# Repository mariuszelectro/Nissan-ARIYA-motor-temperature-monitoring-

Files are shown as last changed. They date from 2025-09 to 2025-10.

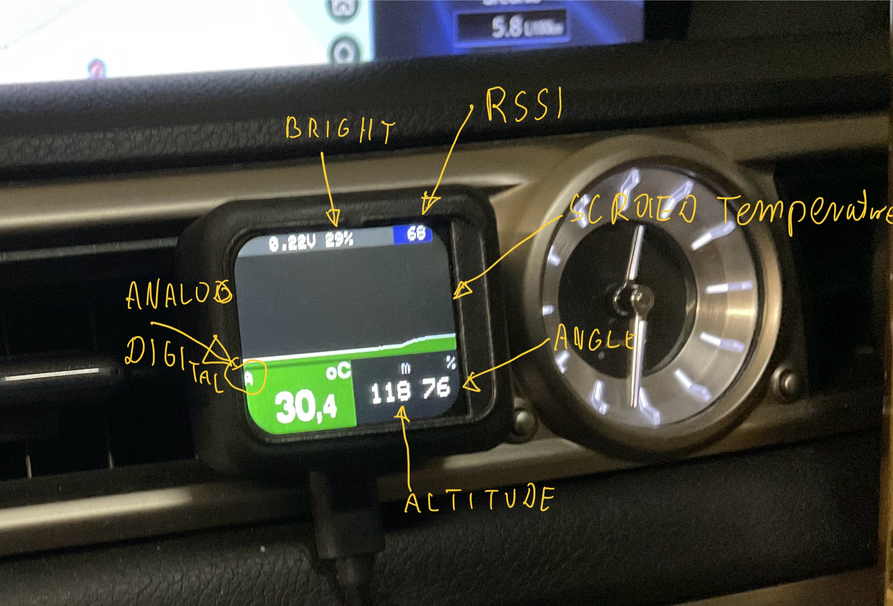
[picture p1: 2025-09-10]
ExtraInfo/IMG_2104.jpeg

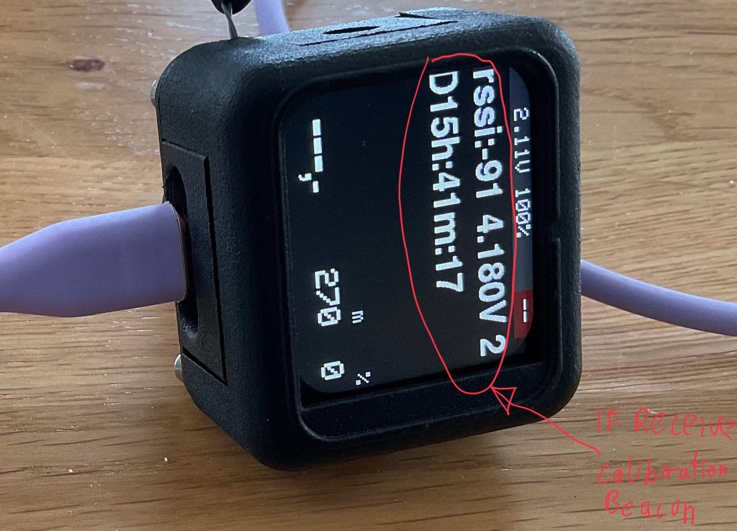
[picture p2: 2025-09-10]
ExtraInfo/IMG_2107.jpeg

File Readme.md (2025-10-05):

# Nissan Ariya Electric Motor Temperature Monitor
Kup mi kawę (https://www.buymeacoffee.com/mariuszelectro)

This project aims to create an independent system to monitor the electric motor's temperature in a Nissan Ariya. The system is designed to prevent sudden vehicle shutdowns caused by overheating.
This project was created as hobby not for comercial  use with maximise effect, not method.

---
### Project Background

The Nissan Ariya has a serious software flaw that can lead to dangerous situations. While driving on an incline, the motor's temperature can rise rapidly, and the car's system will cut power without warning. This can cause the vehicle to stop suddenly on a sloped road in the midle, creating a significant road safety hazard. Since there are no off-the-shelf monitoring systems available to address this problem, I've decided to build one myself.

---
### Key Features

* **Dual Temperature Sensors:** The system uses two diffrent sensors for precise temperature measurement. First Analg PT100, second digital DS18B20
* **Wireless Data Transmission:** Temperature status is sent wirelessly in real-time, trough BLE
* **Temperature Trend Analysis:** The software analyzes the rate of temperature increase, not just the current temperature level, which helps predict potential overheating events.
* **Fast Data Refresh:** Status information is refreshed and analyzed in less than one second.
* **Receiver Unit:** The receiver is equipped with a 1.69" LCD, a buzzer for alerts, a barometric pressure sensor to display altitude, and an inclinometer to show the road's tilt.
* **Receiver function:** The receiver present tempeperature as osciloscope digram for easy understand trends, alitude, and road's tilt.
* **Smart Functions:** A photoresistor automatically adjusts the display's brightness and can also be used as a button to silence the alarm.
* **Calibrator:** Optional Third party used for calibrate sensors.
* **Custom Housing:** All enclosures were designed using 3D modeling and are printed with MJF technology using Nylon for durability.
* **Cost-Effective:** Most of the necessary components can be purchased online at low prices.
* **AI-Powered Code:** A significant portion of the code was developed with the assistance of Gemini AI, but tested and coreted with me.

### Category	Technologies/Skills Demonstrated
* **Electronics Design:** Design of devices containing Analog Circuits and Digital Circuits using Microcontrollers.
* **PCB Design:** Professional PCB Design using Altium Designer (Printed Circuit Board layout).
* **Software & Programming:** Programming in C/C++ (real-time logic, BLE communication, and data analysis).
* **Electro-Mechanical:** Design	Electro-Mechanical Design and physical integration of electronics into custom enclosures.
* **3D Modeling & Enclosures:** 3D Modeling of custom enclosures using FreeCAD, with subsequent manufacturing via MJF 3D Printing.
* **Communication& Data:** Bluetooth Low Energy (BLE) implementation and custom algorithm development for Temperature Trend Analysis.

* * **My contact:** mariuszelectro@gmail.com

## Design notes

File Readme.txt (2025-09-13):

Environment:
ardiuno IDE for upload code
Version: 2.3.6
Date: 2025-04-09T11:26:55.498Z
CLI Version: 1.2.0
------------------
Compile and Editor Eclipse C++ and extension Sloeber https://marketplace.eclipse.org/content/sloeber-arduino-plugin-eclipse 
--------------------------------------------
platform Seeed nRF52 boards version 1.1.10  (sense version) for receiver (need high performance of display by SPI) 
--------------------------------------------
libraries:
Adafriut BMP280 2.6.8
Adafriut BUSIO 1.17.2
Adafriut GFX Library 1.12.1
Adafriut NeoPixel 1.15.1
Adafriut ST7735 and ST7789 Library 1.11.0
Adafriut Unified Sensor 1.1.15
Seeed Arduino LSM6D3 2.0.4  (from SEEED github) please don't add or remove tinyUSB !!!!
----------------------------------------------------------------------------------------
other library installed used form other part of project like transmiter or calibrator
MaximWire by xeno 1.0.3
ArdiunoBLE 1.4.0  (pls don't update! not work in my case )
Adafriut BlueFruitLE nRF51 1.10.0
NRF52_MBED_Timer by Khoi Hoang 1.4.1
NRF52_Timerinterrupt by Khoi Hoang 1.4.2
ardiuno-NVM by frank Holz 0.9.1 (with source code deep modyfication) for future use, now not used 
-----------------------------------------------------------------------------------
platform  Seeed nRF52 mbebd enabled Boards 2.9.3 (for transmiter) 
platform Seeed nRF52 boards version 1.1.10 (for calibrator)

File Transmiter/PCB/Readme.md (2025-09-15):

Here yu will finad all fiels to make an PCB. you can order this usind any suplier.
Thre are 4 layer PCB production gerber, schematic and other files neccessyry for this project. 
Enjoyed.

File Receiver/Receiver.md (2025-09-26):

### **1. Main Module**

---

* **Name:** XIAO nRF52840 Sense
* **Key Features:**
    * Built-in 6-axis Inertial Measurement Unit (IMU) based on a gyroscope and accelerometer for motion and orientation measurement.
    * Bluetooth Low Energy (BLE) module for wireless communication with the transmitter.

---

### **2. Display**

---

* **Type:** 1.69-inch LCD display (based on the [Waveshare 1.69inch LCD Module](https://www.waveshare.com/wiki/1.69inch_LCD_Module))
* **Interface:** Communicates via an SPI (Serial Peripheral Interface) bus.
* **Function:** Used for visualizing data, such as sensor measurements, device status, or other project information.

---

### **3. Sensors**

---

* **Pressure and Temperature Sensor:**
    * **Name:** BMP280 (based on the [HiLetgo BMP280](https://www.amazon.com/HiLetgo-Precision-BMP280-3-3-Atmospheric-Pressure/dp/B01ICN5QPU?th=1))
    * **Characteristics:** A barometric sensor that measures atmospheric pressure for altitude calculation, i2c imtrface. Requires a version with two mounting holes for mechanical stabilization of the XIAO module within the enclosure.
    * **Function:** Used **exclusively** for measuring altitude based on pressure readings.

* **Photoresistor:**
    * **Name:** GL5537 (5537 series)
    * **Characteristics:** A light sensor whose resistance changes with light intensity. 5 mm diameter. ([Link to GL5537 photoresistor](https://juriedengineering.com/products/gl5537-photo-light-sensitive-resistor-photoresistor-55375mm))
    * **Function:** Used to measure ambient light levels.

---

### **4. Audio Components**

---

* **Buzzer:**
    * **Type:** A passive buzzer, converted to active.
    * **Characteristics:** 12mm x 7.5mm in size.
    * **Function:** Used to generate audio signals, alarms, or notifications.

---

### **5. Enclosure and Power Supply**

---

* **Type:** A two-part screw-fastened enclosure.
* **Production Technology:** Printed in **MJF** (Multi Jet Fusion) 3D technology.
* **Function:** Provides precise and secure mechanical mounting for all internal electronic components.
* **Mounting:**
    * **Options:** Magnetic or screw-based mounting.
    * **Location:** Car air vent holder or a standard magnetic mount.
* **Power Supply:** USB-C port.
* **Power Consumpion:** 20mA@5V in dark mode, 50mA@5V in Bright mode

---

### **6. Software Functionality**

---

* **BLE Communication:**
    * **Mode:** The device operates in **passive listener** (beacon passive listener) mode.
    * **Characteristics:** It does not establish an active Bluetooth (BT) connection in any profile. It receives broadcast data from an external measurement beacon.
    * **Received Data:**
        * Temperature from an analog sensor.
        * Temperature from a digital sensor.
        * Fan status.
        * Alarm status.
        * A control counter (ensures data is not duplicated).

* **User Interface (LCD Display):**
    * **Screen Structure:** Divided into several sections.
    * **Sections:**
        * **Title Bar:** Contains the title and **status flags** (e.g., connection status, alarm).
        * **RSSI Section:** Displays the signal strength (RSSI) of the transmitter.
        * **Temperature Oscillogram:** Graphical bars drawn on the screen corresponding to the measured temperature value. They automatically scroll to the left every second. This uses the **display controller's hardware mechanisms**.
        * **Temperature Value:** A numerical indication of the current temperature.
        * **Altitude:** Displays the current altitude.
        * **Road Incline Angle:** The road's incline angle value, shown in a percentage.
    * **Dynamic Backgrounds:** The oscillogram and temperature value sections have defined background colors that change depending on the measured temperature range.

* **Photoresistor Operation:**
    * **Function 1 (Brightness):** Measures external light intensity for automatic screen brightness adjustment (dark and light modes).
    * **Function 2 (Virtual Button):** Acts as a button for calibration. Activated by covering it for 10 seconds after the vehicle starts.
    * **Function 3 (Alarm):** Allows the user to silence an active alarm.
    * **Note:** All measurements for brightness and "presses" are filtered in software to prevent flickering or accidental triggers.

* **Buzzer Operation:**
    * **Characteristics:** Active and dynamic.
    * **Dependencies:** The tone and length of the generated sound depend on the type of alarm and any further temperature increase. The duration and tone of each beep is variable.

* **Sensor Calibration:**
    * **Sensor Types:** Barometric and position (gyroscope/accelerometer).
    * **Calibration Methods:**
        1.  **Button Press:** Manual calibration activation.
        2.  **Signal Reception:** Automatic calibration upon receiving a signal from a dedicated calibration beacon "Calibrator"
    * **Calibration Process:**
        * **Inclinometer:** Zeros the incline angle readings to a zero position, regardless of the device's current orientation.
        * **Pressure:** Compensates absolute pressure for a fixed altitude of 270 meters above sea level.
    * **Calibration Availability:** The calibration function is available **only within a 10-second time window after the device is powered on**.
    * **Accuracy:** The altitude measurement has an accuracy of approximately 1 meter.

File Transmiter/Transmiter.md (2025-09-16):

# Nissan Ariya - Advanced Electric Motor Temperature Monitor

This project aims to create an independent, intelligent system for monitoring and actively managing the electric motor's temperature in a Nissan Ariya. The primary goal is to prevent sudden, dangerous vehicle shutdowns caused by overheating.

---

### Transmitter Assumptions and Functions

The transmitter is the core of the system, focusing on advanced data analysis and control that goes beyond simple temperature readings.

#### Inputs and Power
* **Inputs:** The transmitter has three inputs:
    1.  A dedicated input for a **PT100** sensor.
    2.  An input for a digital **DS18B20** sensor.
    3.  A power input ranging from **12-16V** from the car's on-board network.
* **Power Management:** A comparator-based circuit monitors the 12V battery voltage. The system activates at **13.6V** and enters a low-power sleep mode at **12.9V** (with hysteresis), consuming only 3µA in standby mode and 30mA in opertional mode 

#### Measurement Circuitry
* **PT100 Measurement:** The input circuit consists of a Wheatstone bridge with three **105R resistors** (0.1% tolerance, low ppm). This specific resistance value was chosen because the project focuses on temperatures **above 15°C**. The bridge is powered by a ~2mA current source, and the resulting voltage signal is amplified by an instrumental amplifier.
* **Signal Conversion:** The voltage is converted to a **0-12V** level and then fed through a voltage divider to the measurement input of a **XIAO nRF52840** module.
* **Data Processing:** The XIAO module samples the voltage every few milliseconds, applies filtering and advanced averaging, and then converts the voltage value into a temperature reading. It also handles the digital DS18B20 sensor.

---

### Sensor Selection: Why Two?

Although using a single, digital **DS18B20** sensor would simplify the circuit, past experience shows it's susceptible to interference from strong magnetic fields, which causes it to **freeze or hang**. To ensure reliability and continuous measurements, a redundant sensor setup with two different types of sensors was implemented. **By cycling the power, the system can restore the sensor to operation.** The system intelligently selects the proper, available sensor by analyzing both signals.

---

### Advanced Logic and Control
* **Sensor Selection:** The system analyzes data from both sensors, always selecting the one that is available and has a higher temperature reading.
* **Trend Analysis:** The software analyzes the temperature's upward trend, predicting its increase over a **30-second period**.
* **Early Warning:** An alarm is activated well in advance if the trend analysis predicts the temperature will reach the critical limit of **70°C**. You can set another one.
* **Actuator Control:** An output is available to control an external actuator, such as an **additional cooling fan**. The fan's activation is also based on the temperature trend analysis.
* **Analog Output:** An analog output signal (0-12V) is provided for diagnostic purposes, where **10V corresponds to 100°C**.
* **Control Method:** The fan can be controlled via a hardware comparator or by software.

#### Communication and Housing
* **BLE Beacon Mode:** The XIAO module operates as a BLE "beacon," transmitting measurement data, alarm flags, fan status, and a running counter as dynamic advertising data. This allows it to be tracked with a standard Bluetooth scanner on a phone.
* **Debug Mode:** When connected, the module enters a debug mode (SSP BLE profile ), sending data to the Bluefruit Connect application to generate plots on canvas, from both sensors.
* **Antenna:** The custom PCB version includes a modified antenna layout with a u.FL connector for an external antenna, providing better range than the factory one.
* **Enclosure:** The housing is 3D printed using MJF technology with black nylon powder, resulting in a very solid and durable enclosure with 3mm thick walls, labyrinthine seals, and cable holders.
* **Availability:** The PCB schematic BOM and layout you can find in PCB section . While others can print the model using different technologies, the precise fit and accuracy of the MJF process may not be achievable.

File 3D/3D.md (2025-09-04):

### 3D Models (Source Files)

Here you will find the 3D models (source files) created in **FreeCAD**. The models are designed for 3D printing.

In the future, these models will be supplemented with `.stl` files.

You can open the `.FCStd` file in FreeCAD to make changes and export the models of individual components.

---
#### List of 3D Models

* Car air vent mount
* LCD display housing (top and bottom parts)
* Transmitter sensor housing (top and bottom parts)

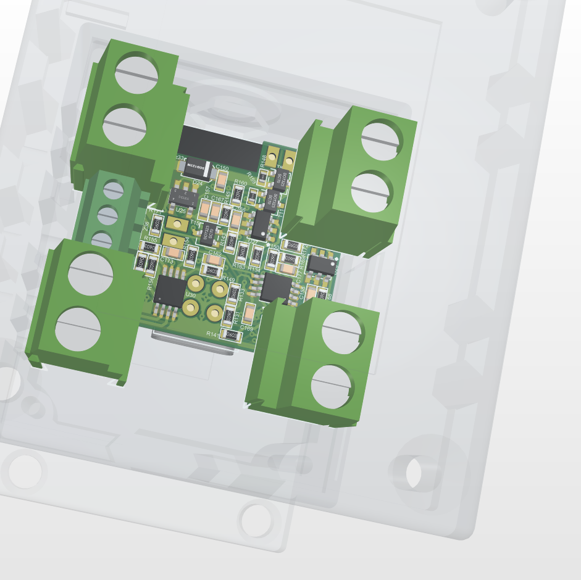
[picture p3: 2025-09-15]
ExtraInfo/YpadjyPY0odjasRK.png

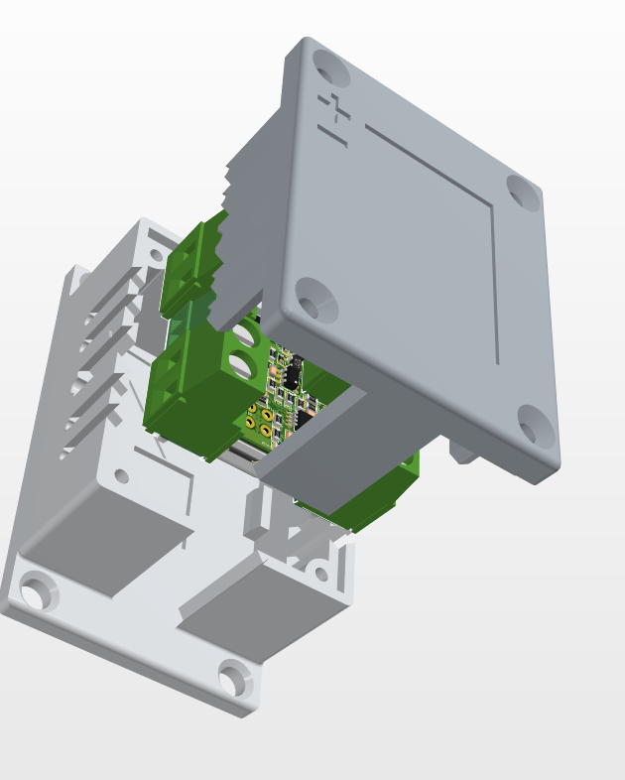
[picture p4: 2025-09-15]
ExtraInfo/zAJwUcnX5S6KeYe2.png

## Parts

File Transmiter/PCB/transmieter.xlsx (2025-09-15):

Comment | Description | Designator | dostawca | Footprint | Quantity
1u/16V 10% X7R | C | C150, C157, C162, C167, C168, C169, C173 |  | 0603-CAP | 7
100n/16V 10% X7R | C | C158, C166, C174, C177 |  | 0603-CAP | 4
PMEG150G20ELRX | 1A 100V (min) | D24 |  | SOD123W | 1
S-GW120 | LED | D25 |  | 0805-LED-G | 1
UCLAMP3301D.TCT | dioda zenera 3.3V | D26 |  | SOD323 | 1
300K 1% | REZ | R24, R148, R159, R162 |  | 0402-REZ | 4
10K 0,1% 25ppm | REZ | R131, R133, R141 |  | 0603-REZ | 3
4M7 1% | REZ | R134, R172 |  | 0603-REZ | 2
390R 1% | REZ | R142 |  | 0603-REZ | 1
220K 1% | REZ | R143, R168 |  | 0603-REZ | 2
191K 1% | REZ | R144 |  | 0603-REZ | 1
150K 1% | REZ | R145 |  | 0603-REZ | 1
105R 01% 25ppm | REZ | R146, R147, R151 |  | 0603-REZ | 3
0R | REZ | R149 |  | 0603-REZ | 1
1M 1% | REZ | R150, R154, R163 |  | 0603-REZ | 3
DNP | REZ | R155, R158, R171 |  | 0603-REZ | 3
931R 0,1% 25ppm | REZ | R156, R157 |  | 0603-REZ | 2
1M5 1% | REZ | R160 |  | 0603-REZ | 1
45K3 1% | REZ | R161 |  | 0603-REZ | 1
4K7 1% | REZ | R164 |  | 0603-REZ | 1
10K 1% | REZ | R165 |  | 0603-REZ | 1
3k9 1% | REZ | R167 |  | 0603-REZ | 1
270K 1% | REZ | R169 |  | 0603-REZ | 1
PJC7439 |  | T8, T16 |  | sot-323 | 2
2N7002BKW.115 |  | T11, T17, T18 |  | sot-323 | 3
AO7407 |  | T15 |  | sot-323 | 1
TPS7A2450DBVR | 200-mA, 18-V, ultra-low-IQ, low-dropout (LDO) voltage regulator with enable | U25 |  | SOT223-5 | 1
TLV9352 | dual op ampl 40V TLV9352IDGKR | U26 |  | msop8 | 1
MCP65R46T-1202E/CHY | komparator +ref | U27, U29 |  | sot23-6 body2.2x2.7mm | 2
xiao-nRF52840 | xiao-nRF52840 | U28 |  | XiAO-nRF52840 | 1
INA333 | AD623 | U30 |  | msop8 | 1
ARK2 |  | z32, z33, z34, z35 | [NoParam], wurth 691502710002 | ARK2 5.0mm | 4
wurth 691212710003 |  | Z36 |  | ARK 3x2.54mm | 1

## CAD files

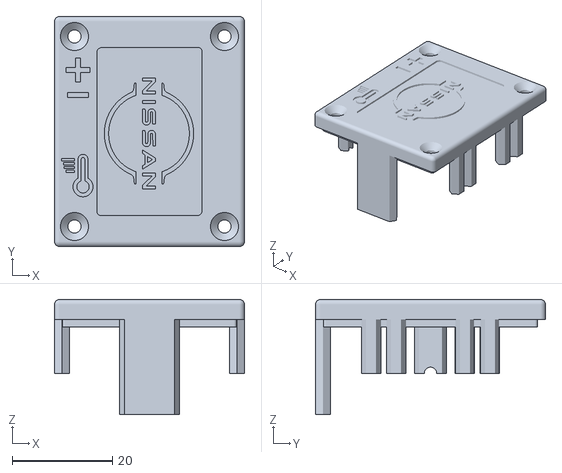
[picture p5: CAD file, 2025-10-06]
3D/TempSensorPTC100_wieczko-Body.stl
38.0 x 46.0 x 23.0

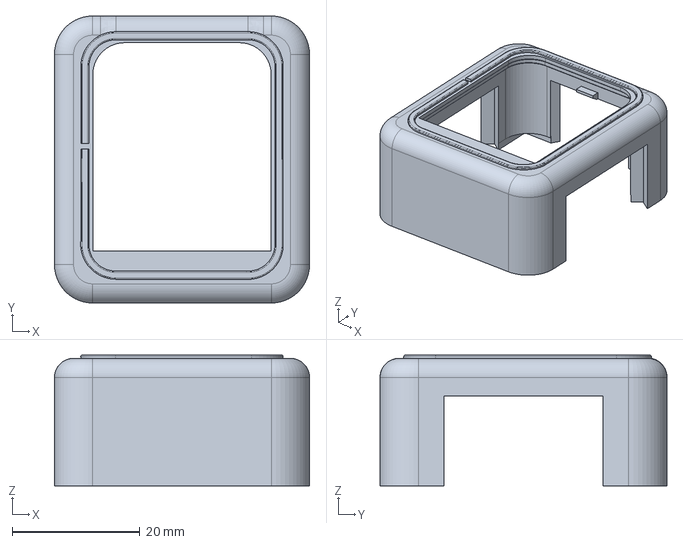
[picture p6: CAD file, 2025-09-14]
3D/LCD_topV2.FCStd
40.0 x 45.0 x 20.5 mm

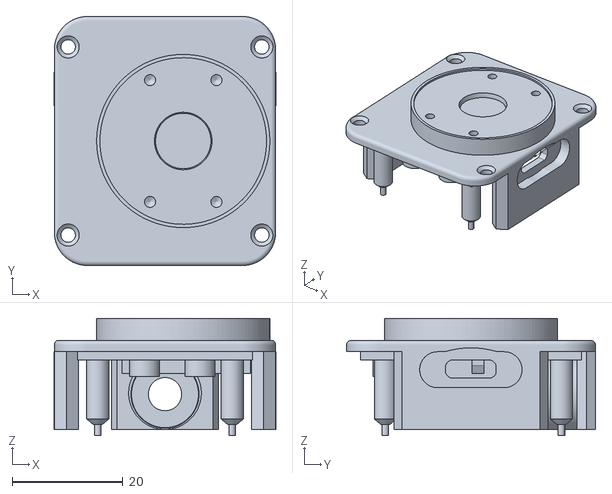
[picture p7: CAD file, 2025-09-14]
3D/LCD_bottomV1-Body.stl
40.0 x 45.0 x 21.2

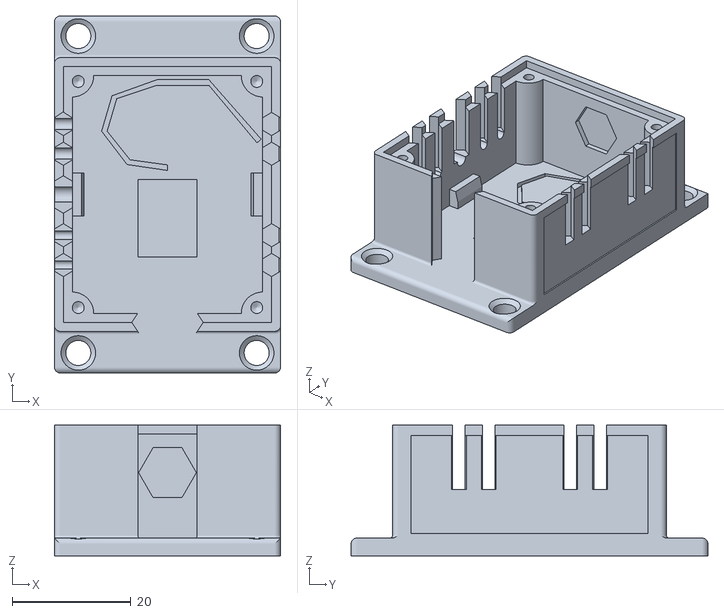
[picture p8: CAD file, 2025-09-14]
3D/TempSensorPTC100v1-Body.stl
38.0 x 60.0 x 22.0

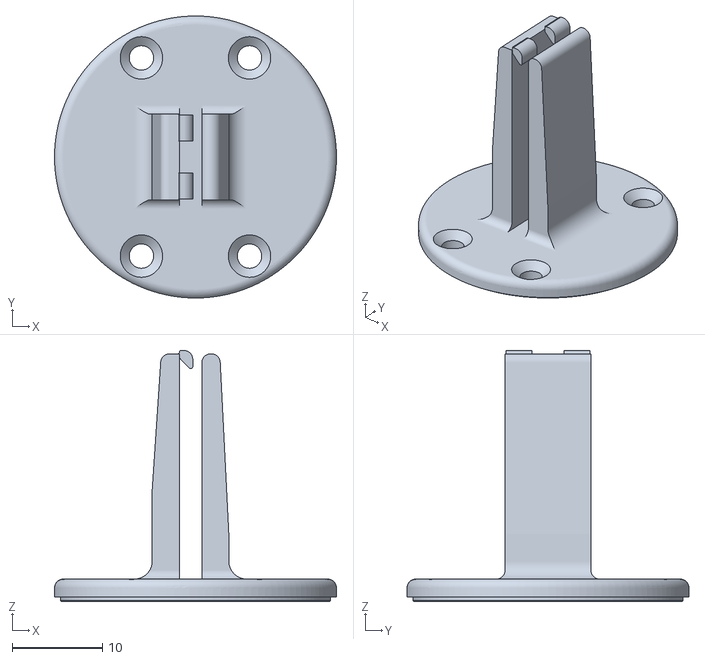
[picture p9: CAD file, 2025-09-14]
3D/uchwyt-Bodyv1.stl
31.3 x 31.3 x 27.9

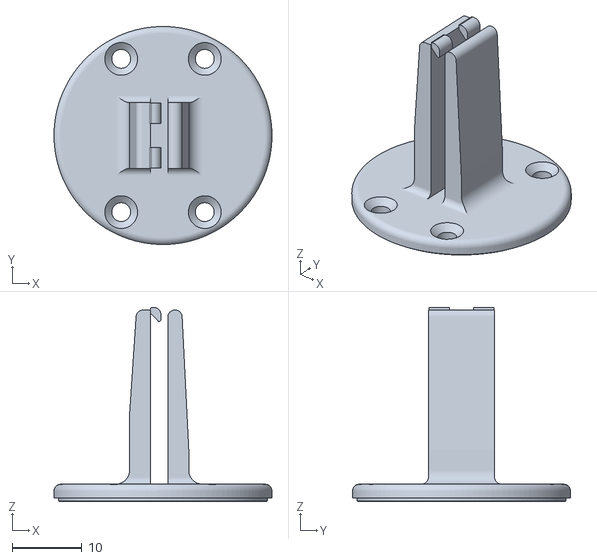
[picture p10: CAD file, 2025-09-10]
3D/uchwyt-Body.stl
31.3 x 31.3 x 27.9

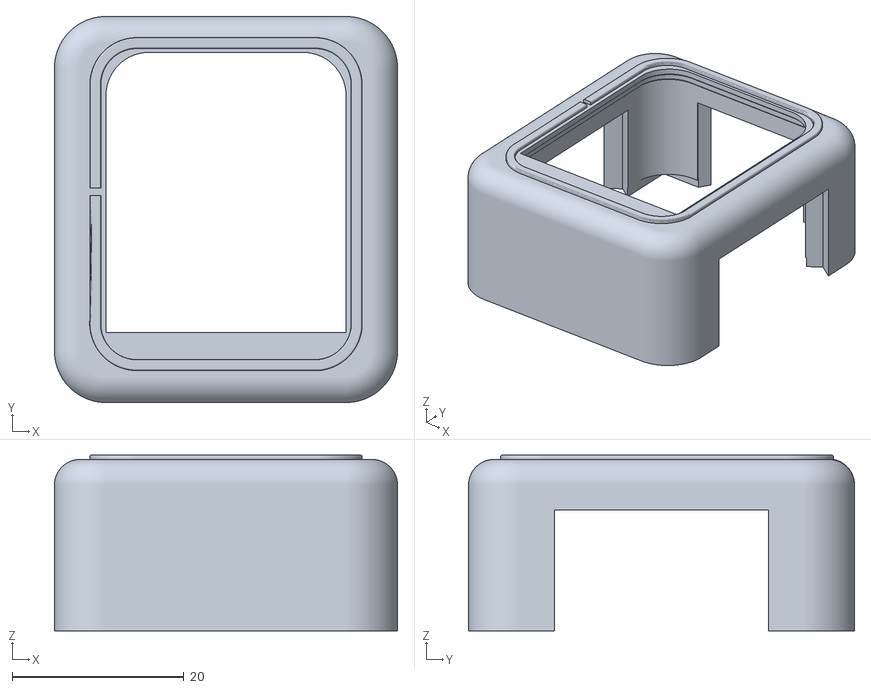
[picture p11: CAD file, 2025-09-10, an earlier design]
3D/LCD_topV1-Body.stl
40.0 x 45.0 x 20.5

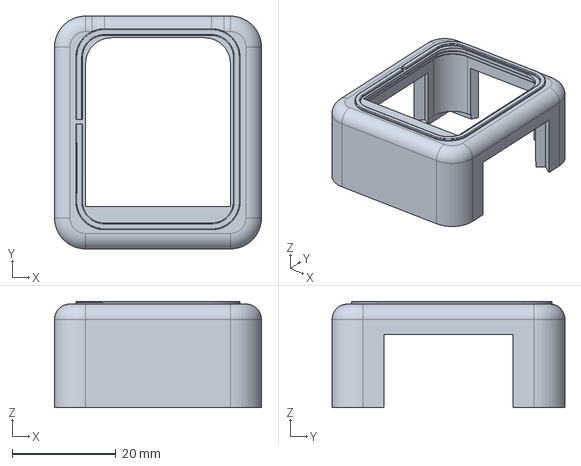
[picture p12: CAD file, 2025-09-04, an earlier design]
3D/LCD_topV1.FCStd
40.0 x 45.0 x 20.5 mm

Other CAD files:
3D/TempSensorPTC100_wieczko.FCStd
3D/LCD_topV2-Body.stl
3D/LCD_bottomV1.FCStd
3D/TempSensorPTC100.FCStd
3D/uchwytv1.FCStd
3D/TempSensorPTC100v1.FCStd
3D/TempSensorPTC100-Body.stl
3D/uchwyt.FCstd

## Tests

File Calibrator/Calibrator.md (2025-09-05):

---
# Calibrator

Calibrator is a smart auxiliary device designed for automatic calibration of a vehicle's altitude and road incline sensors. It uses **Bluetooth Low Energy (BLE)** technology to communicate with the car, ensuring precise settings right after the ignition.

## How it Works

The Calibrator device is placed in a garage or another stable, fixed location. When the car is started, the vehicle's system actively scans its surroundings for a calibration beacon for the first 10 seconds.

* **Barometric Sensor (Altimeter) Calibration:** If the signal is detected, the vehicle's barometric sensor is automatically calibrated to a predefined, fixed altitude.
* **Inclinometer Calibration:** At the same time, with the vehicle on a level surface, the software sets the inclinometer's reading to 0 degrees, eliminating measurement errors.

After a successful calibration, a scrolling message appears on the car's receiver, confirming the calibration and displaying the beacon's **battery voltage** and **uptime** since its last power-on.

## Technical Aspects

* **Platform:** The project is built on the energy-efficient **XIAO nRF52840** platform, which provides high performance with minimal power consumption.
* **Power:** The device is powered by a single **18650 battery**. Thanks to its exceptional power efficiency, the battery can operate the device for **5-10 years** without needing to be recharged. If needed, it can be easily topped up via the built-in **USB-C** port.
* **BLE Communication:** The Calibrator device broadcasts a beacon signal that includes real-time information about its **current battery voltage** and **uptime**, allowing you to monitor the device's status directly from the car.

---

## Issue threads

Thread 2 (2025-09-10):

Receiver virtual button not work when is very bright

mariuszelectro, 2025-09-10:
Virtual button need update. When ambient light is high luminance there is no possibles do calibration or mute alarm.
Why because finger is no enough for cut light and activate sensor.
Solution introduce dynamic level of activate instead of fixed.

mariuszelectro, 2025-09-27:
Resolved by inroducing dynamic level depend on ambient bright.

Closed 2025-09-27.

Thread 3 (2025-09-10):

Road profile not working

mariuszelectro, 2025-09-10:
Imu sensor is sensitive for vibration and acceleration, so road profile is absolute false. solution introduce hardware filter for reduce noise, use advanced filtering for compensate.

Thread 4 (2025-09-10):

Receiver save calibration

mariuszelectro, 2025-09-10:
Save gyro relative x,y,z axis seems like sometimes not save or read properly. Need deeper investigation.

Closed 2025-09-27.

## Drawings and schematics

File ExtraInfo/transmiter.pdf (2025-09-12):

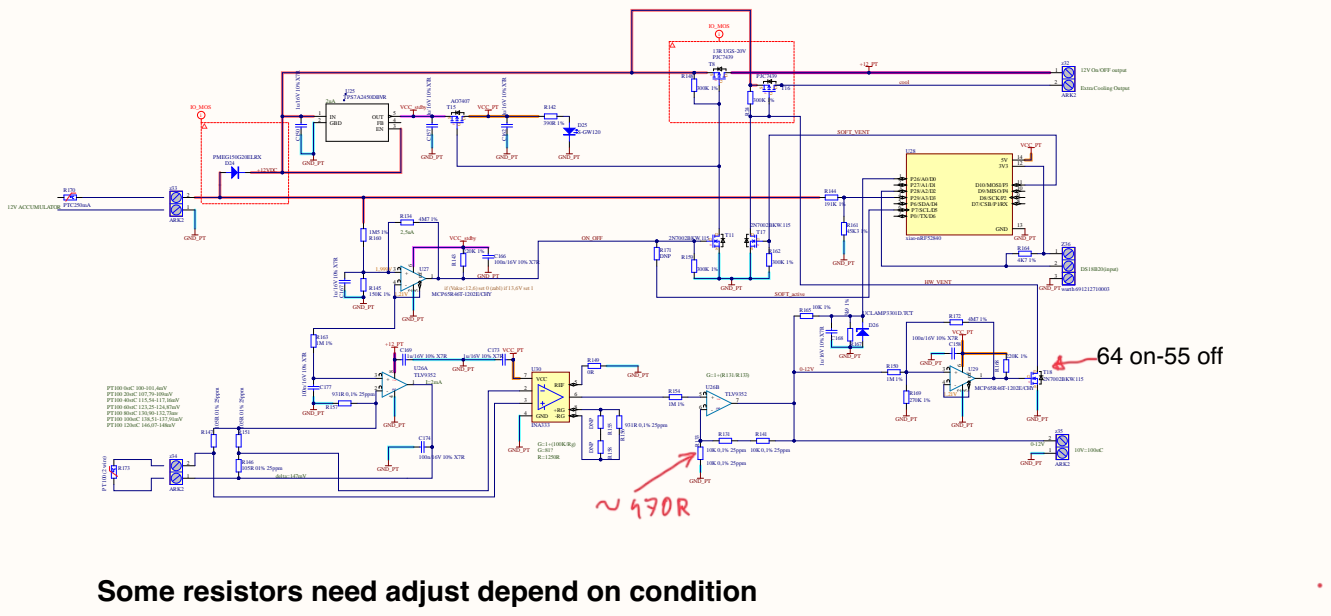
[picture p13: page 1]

U25 TPS7A2450D 2uA B VR | R14 8 | J C743 9 | 21 cool

S O F T_a c t ive | R164

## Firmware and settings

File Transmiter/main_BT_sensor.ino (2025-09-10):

// --------------------------------------------------
// Brief design description:
// Single DS18B20 Temperature Sensor and Analog Voltage Reading with
// Bluetooth Low Energy (BLE) Nordic UART Service (NUS).
// Optimized for Bluefruit Plotter (Voltage, Temperature) and
// Advanced Temperature Alerting with Projected Trend Detection.
// Dynamic BLE Advertising: Updates every 1s with Temp, ADC, and Alarm status.
// Synchronized communication: UART BLE TX and Advertising are 500ms apart.
// LED Behavior:
// - Red LED: Blinks 100ms ON / 900ms OFF (1s cycle). (Control inverted: HIGH=ON)
// - Blue LED: ON when connected. OFF when disconnected/advertising. (Control LOW=ON)
// --------------------------------------------------
// Version: 1.31.0 (Added '----' for unavailable DS18B20 in advertising name)
// Date   : 17/07/2025
// Author : Fire Fox & Gemini AI
// --------------------------------------------------
// Environment:
// - IDE Arduino v2.x (or compatible)
// - Win 10 Pro
// --------------------------------------------------
// Board model: XIAO nRF52840 sense
// --------------------------------------------------
// Useful references:
// https://www.arduino.cc/reference/en/libraries/arduinoble/
// https://github.com/arduino-libraries/ArduinoBLE/
// Nordic UART Service (NUS) UUIDs:
// Service: 6E400001-B5A3-F393-E0A9-E50E24DCCA9E
// RX Characteristic: 6E400002-B5A3-F393-E0A9-E50E24DCCA9E (Write)
// TX Characteristic: 6E400003-B5A3-F393-E0A9-E50E24DCCA9E (Read | Notify)
// --------------------------------------------------

#include <ArduinoBLE.h>            // ArduinoBLE v1.4.0 (or newer)
#define MAXIMWIRE_EXTERNAL_PULLUP  // Use if you have an external pull-up resistor
#include <MaximWire.h>             // MaximWire v1.0.3

#include "NRF52_MBED_TimerInterrupt.h"  // NRF52_MBED_TimerInterrupt v1.4.1
#include <stdlib.h>                     // Still good to keep for general utility
#include <cstdio>                       // Required for snprintf
#include <cmath>                        // Required for round() or other math functions
#include "AnalogTempSensor.h"


// ==================================================
// GLOBAL VARIABLES - DEFINITIONS
// ==================================================
const int ledRedPin = LED_BUILTIN;  // Red LED (D7 on XIAO nRF52)
const int ledBluePin = LEDB;        // Blue LED (D6 on XIAO nRF52)
const int coolingPin = D5;          // Pin controlling cooling (e.g., a relay)

//#define BLEDebug          //nie wyswietlmy info od BLE

// Variables for red LED blinking
#define RED_LED_BLINK_INTERVAL_MS 100  // Timer interval for red LED

unsigned long previousMillisAnalogRead = 0;
volatile unsigned int redLedPhaseCounter = 0;  // Red LED blink phase counter

// Analog input(s) definition



// Dwie niezależne zmienne dla temperatur
static float analogTemperature = NAN;
float ds18b20Temp = NAN;
float inputVoltage = NAN;

// DS18B20 temperature sensor (for a SINGLE sensor)
MaximWire::Bus bus(2);          // OneWire bus on pin D2
MaximWire::DS18B20 tempSensor;  // Object for a single DS18B20 sensor
bool ds18b20_found = false;     // Flag if sensor was found and initialized

// Timers for LEDs (ITimer0 for red)
NRF52_MBED_Timer ITimer0(NRF_TIMER_3);  // For red LED

// Timer for sensor readings and UART BLE TX
unsigned long previousMillisSensorRead = 0;
const long int TMR_READ_SENSORS_MS = 1000;  // Read sensors and send UART BLE every 1s

// Variable to control blue LED after sensor readings
const long int BLUE_LED_DURATION_MS = 50;  // Blue LED blink duration
unsigned long blueLedToggleMillis = 0;     // Time when blue LED was last turned on for a blink

// BLE: board name and device name definition
const char* boardName = "TempSensor";
const char* devName = "AryiaMariusz";  // Pełna nazwa urządzenia (widoczna po połączeniu)

// BLE: Nordic UART Service (NUS) definition
BLEService uartService("6E400001-B5A3-F393-E0A9-E50E24DCCA9E");
BLECharacteristic rxCharacteristic("6E400002-B5A3-F393-E0A9-E50E24DCCA9E", BLEWriteWithoutResponse | BLEWrite | BLERead, 20);
BLECharacteristic txCharacteristic("6E400003-B5A3-F393-E0A9-E50E24DCCA9E", BLERead | BLENotify, 20);

// ==================================================
// VARIABLES FOR TREND DETECTION AND NOTIFICATIONS
// ==================================================
#define TREND_WINDOW_SECONDS 30
#define TEMP_HISTORY_SIZE TREND_WINDOW_SECONDS
#define PROJECTION_TIME_SECONDS 10

// Dwie niezależne historie dla każdego czujnika
float tempHistoryDS[TEMP_HISTORY_SIZE];
unsigned long timeHistoryDS[TEMP_HISTORY_SIZE];
int historyIndexDS = 0;
bool historyFullDS = false;

float tempHistoryAnalog[TEMP_HISTORY_SIZE];
unsigned long timeHistoryAnalog[TEMP_HISTORY_SIZE];
int historyIndexAnalog = 0;
bool historyFullAnalog = false;

// Alarm thresholds
const float TEMP_HIGH_THRESHOLD = 70.0;
const float COOLING_OFF_THRESHOLD_PERCENT = 0.10;
float coolingOffThreshold;

// Flagi statusu alarmu dla każdego źródła
bool ds18b20AlertActive = false;
bool analogAlertActive = false;

char alarmStatusChar = 'N';      // 'A' for alarm, 'N' for no alarm
char d5ControlStatusChar = 'n';  // 'W' for fan ON, 'n' for fan OFF
unsigned char MyCounter = 0;     // Twój licznik, brawo za dodanie!

// ==================================================
// FUNCTIONS SECTION
// ==================================================

// Helper function to send notifications via BLE UART
void sendNotification(String message) {
  if (txCharacteristic.subscribed()) {
    #ifdef BLEDebug
    Serial.print("INFO BLE TX Notification: Sending: '" + message + "' (Length: " + message.length() + " bytes)");
  #endif
    if (message.length() > 20) {
      Serial.println(" - INFO: Notification > 20 bytes. Relying on DLE for full delivery.");
    }
    txCharacteristic.writeValue(message.c_str());
    #ifdef BLEDebug
    Serial.println(" - Sent OK!");
    #endif
  } else {
    #ifdef BLEDebug
    Serial.println("INFO BLE TX: Not subscribed, notification not sent.");
    #endif
  }
}

// TIMER0: interrupt handler definition (for red LED)
void TimerHandler0() {
  redLedPhaseCounter++;
  if (redLedPhaseCounter == 1) {
    digitalWrite(ledRedPin, HIGH);
  } else if (redLedPhaseCounter == 10) {
    digitalWrite(ledRedPin, LOW);
    redLedPhaseCounter = 0;
  }
}

// Function to update advertising data
void updateAdvertisingData() {
  // Bufor na temperaturę analogową w formacie "Axx.x" (zawsze 5 znaków: A + 3 cyfry + kropka + 1 cyfra)
  char anTempStr[7];
  if (isnan(analogTemperature)) {
    strcpy(anTempStr, "A----");
  } else {
    int intPart = (int)analogTemperature;
    int decPart = abs((int)(round((analogTemperature - intPart) * 10)));
    if (intPart < 10) {
      snprintf(anTempStr, sizeof(anTempStr), "A  %d.%1d", intPart, decPart);
    } else if (intPart < 100) {
      snprintf(anTempStr, sizeof(anTempStr), "A %d.%1d", intPart, decPart);
    } else {
      snprintf(anTempStr, sizeof(anTempStr), "A%d.%1d", intPart, decPart);
    }
  }

  // Bufor na temperaturę cyfrową w formacie "Cyy.y" (zawsze 5 znaków)
  char dsTempStr[7];
  // POPRAWKA: Dodajemy sprawdzenie NaN dla DS18B20 w nazwie reklamowej
  if (isnan(ds18b20Temp)) {
    strcpy(dsTempStr, "C----");
  } else {
    int intPart = (int)ds18b20Temp;
    int decPart = abs((int)(round((ds18b20Temp - intPart) * 10)));
    if (intPart < 10) {
      snprintf(dsTempStr, sizeof(dsTempStr), "C  %d.%1d", intPart, decPart);
    } else if (intPart < 100) {
      snprintf(dsTempStr, sizeof(dsTempStr), "C %d.%1d", intPart, decPart);
    } else {
      snprintf(dsTempStr, sizeof(dsTempStr), "C%d.%1d", intPart, decPart);
    }
  }

  // Tworzenie dynamicznej nazwy reklamowej w formacie "Axx.x Cyy.y ASC S Z"
  // Przykład: "A 25.1 C 24.8 NN0" (AS=N, CS=n, MyCounter=0) lub "A---- C---- AN0"
  // Długość: 5 (anTempStr) + 1 (spacja) + 5 (dsTempStr) + 1 (spacja) + 1 (AS) + 1 (CS) + 1 (MyCounter) = 15 znaków + null terminator.
  char advNameBuffer[20];  // Bufor (nadal zostawiamy większy bufor na wszelki wypadek)
  int len = snprintf(advNameBuffer, sizeof(advNameBuffer), "%s %s %c%c%d",
                     anTempStr, dsTempStr, alarmStatusChar, d5ControlStatusChar, ((MyCounter++) % 10));

  Serial.print("DEBUG ADV: Analog Temp Str: '");
  Serial.print(anTempStr);
  Serial.print("' DS18B20 Temp Str: '");
  Serial.print(dsTempStr);
  Serial.print("' Alarm Status: '");
  Serial.print(alarmStatusChar);
  Serial.print("' D5 Control Status: '");
  Serial.print(d5ControlStatusChar);
  Serial.println("'");
  Serial.print("DEBUG ADV: Generated Local Name: '");
  Serial.print(advNameBuffer);
  Serial.print("' (Length: ");
  Serial.print(len);
  Serial.println(" bytes)");

  if (len < sizeof(advNameBuffer) && len >= 0) {
    BLE.setLocalName(advNameBuffer);
    #ifdef BLEDebug
    Serial.println("INFO BLE ADV: Local Name (Advertising Name) set successfully.");
    #endif
  } else {
    #ifdef BLEDebug
    Serial.println("ERROR BLE ADV: Generated Local Name is too long or snprintf failed!");
    #endif
    BLE.setLocalName("ERR");
  }

  // UWAGA: Ta część kodu jest kluczowa. Reklama jest uruchamiana tylko wtedy,
  // gdy urządzenie nie jest połączone.
  if (!BLE.central()) {
    // Sprawdź, czy reklama jest już aktywna. Jeśli tak, zatrzymaj ją przed aktualizacją.
    if (BLE.advertise()) {  // Używamy BLE.advertising() do SPRAWDZANIA statusu
      BLE.stopAdvertise();
      #ifdef BLEDebug
      Serial.println("INFO BLE ADV: Stopped existing advertising to update Local Name.");
      #endif
    }

    BLE.advertise();  // Używamy BLE.advertise() do ROZPOCZĘCIA/WZNOWIENIA reklamy
    #ifdef BLEDebug
    Serial.println("INFO BLE ADV: Started/Resumed advertising with dynamic Local Name and Service UUID.");
    #endif
  }
}

// BLE: connection event handler (callback)
void blePeripheralConnectHandler(BLEDevice central) {
  Serial.print("INFO BLE: Connected to central: ");
  Serial.println(central.address());

  Serial.println("INFO BLE: MTU negotiation handled automatically by ArduinoBLE.");

  BLE.stopAdvertise();
  Serial.println("INFO BLE ADV: Stopped advertising on connect.");
  digitalWrite(ledBluePin, LOW);  // TURN ON blue LED permanently when connected (LOW=ON)
}

// BLE: disconnection event handler (callback)
void blePeripheralDisconnectHandler(BLEDevice central) {
  Serial.print("INFO BLE: Disconnected from central: ");
  Serial.println(central.address());
  Serial.println("INFO BLE ADV: Resuming advertising after disconnect.");

  digitalWrite(ledBluePin, HIGH);  // TURN OFF blue LED permanently when disconnected (HIGH=OFF)
  updateAdvertisingData();
}

// Function to handle writing to RX characteristic (when phone sends data to module)
void rxCharWriteHandler(BLEDevice central, BLECharacteristic characteristic) {
  String receivedData = "";
  if (characteristic.valueLength() > 0) {
    for (int i = 0; i < characteristic.valueLength(); i++) {
      receivedData += (char)characteristic.value()[i];
    }
  }

  Serial.print("INFO BLE RX: Received data: ");
  Serial.println(receivedData);

  if (receivedData.length() > 0) {
    char command = receivedData.charAt(0);
    if (command == '1') {
      Serial.println("INFO: Red LED ON via BLE UART");
      digitalWrite(ledRedPin, HIGH);
    } else if (command == '0') {
      Serial.println("INFO: Red LED OFF via BLE UART");
      digitalWrite(ledRedPin, LOW);
    }
  } else {
    Serial.println("INFO BLE RX: Empty data received.");
  }
}

// Funkcja do analizy trendu dla konkretnego źródła temperatury
float analyzeTemperatureTrend(float currentTemp, float* history, unsigned long* timeHistory,
                              int& historyIndex, bool& historyFull, unsigned long currentMillis) {

  float projectedTemp = currentTemp;

  if (!isnan(currentTemp)) {
    history[historyIndex] = currentTemp;
    timeHistory[historyIndex] = currentMillis;
    historyIndex = (historyIndex + 1) % TEMP_HISTORY_SIZE;
    if (historyIndex == 0) {
      historyFull = true;
    }
  } else {
    historyFull = false;
    historyIndex = 0;
    for (int i = 0; i < TEMP_HISTORY_SIZE; ++i) history[i] = NAN;
  }

  if (historyFull && !isnan(currentTemp)) {
    int oldestIndex = historyIndex;
    float oldestTemp = history[oldestIndex];
    unsigned long oldestTime = timeHistory[oldestIndex];

    if (!isnan(oldestTemp) && currentMillis - oldestTime >= (TREND_WINDOW_SECONDS / 2 * 1000UL)) {
      float timeDiffSeconds = (float)(currentMillis - oldestTime) / 1000.0;
      float tempDiff = currentTemp - oldestTemp;

      if (timeDiffSeconds > 0.1 && tempDiff > 0.0) {
        float tempRateOfChange = tempDiff / timeDiffSeconds;
        projectedTemp = currentTemp + (tempRateOfChange * PROJECTION_TIME_SECONDS);
      }
    }
  }
  return projectedTemp;
}
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
void loop() {
  BLE.poll();

  BLEDevice central = BLE.central();
  int analogReadValue = 0;  //ty przechowywujem wartosć temperaturzy zmierznonej w ADC
  unsigned long currentMillis = millis();

  if (rxCharacteristic.written()) {
    rxCharWriteHandler(central, rxCharacteristic);
  }

  // Kontrolka niebieskiej diody LED
  if (central) {
    digitalWrite(ledBluePin, LOW);  // Włączony, gdy połączono
  } else {
    // Mignij niebieską diodą LED, gdy odczytujemy sensory i nie jesteśmy połączeni
    if (digitalRead(ledBluePin) == LOW && (currentMillis - blueLedToggleMillis >= BLUE_LED_DURATION_MS)) {
      digitalWrite(ledBluePin, HIGH);  // Wyłącz po krótkim czasie
    }
  }
  if (currentMillis - previousMillisAnalogRead >= TMR_READ_ANALOG_MS) {
    previousMillisAnalogRead = currentMillis;
    collectTempProbe();
  }

  if (currentMillis - previousMillisSensorRead >= TMR_READ_SENSORS_MS) {
    previousMillisSensorRead = currentMillis;

    // Odczyty z sensorów

    int analogTemperatureInt = getFilteredAnalogTemperature(&inputVoltage);
  

    if (analogTemperatureInt != -1) {
      analogTemperature = analogTemperatureInt / 100.0;
    }


    Serial.print("Volt_RAW: ");
    Serial.print(analogReadValue);
    Serial.print(", Scaled Volt: ");
    Serial.print(inputVoltage, 2);
    Serial.print("V, Analog Temp: ");
    Serial.print(analogTemperature, 1);
    Serial.println("C");

    if (ds18b20_found) {
      float tempReadingDS18B20 = tempSensor.GetTemperature<float>(bus);
      tempSensor.Update(bus);

      if (!isnan(tempReadingDS18B20)) {
        ds18b20Temp = constrain(tempReadingDS18B20, 0.0, 140.0);
        Serial.print("Temp (DS18B20): ");
        Serial.print(ds18b20Temp, 1);
        Serial.println("C");
      } else {
        Serial.println("ERROR DS18B20: Could not read temperature data! ds18b20Temp is NaN.");
        ds18b20Temp = NAN;
      }
    } else {
      Serial.println("WARNING DS18B20: No sensor initialized or found for reading.");
      ds18b20Temp = NAN;
    }

    Serial.print("DEBUG SENSORS: DS18B20 Temp=");
    Serial.print(ds18b20Temp, 2);
    Serial.print(", Analog Temp=");
    Serial.print(analogTemperature, 2);
    Serial.print(" Current Volt=");
    Serial.println(inputVoltage, 2);

    // Mignięcie niebieskiej diody LED, jeśli nie połączono i są dane
    if (!central && (!isnan(ds18b20Temp) || !isnan(analogTemperature)) && !isnan(inputVoltage)) {
      digitalWrite(ledBluePin, LOW);
      blueLedToggleMillis = currentMillis;
    }

    // Analiza trendu
    float projectedTempDS18B20 = analyzeTemperatureTrend(ds18b20Temp, tempHistoryDS, timeHistoryDS,
                                                         historyIndexDS, historyFullDS, currentMillis);
    float projectedTempAnalog = analyzeTemperatureTrend(analogTemperature, tempHistoryAnalog, timeHistoryAnalog,
                                                        historyIndexAnalog, historyFullAnalog, currentMillis);

    Serial.print("DEBUG TREND: Projected DS18B20 Temp: ");
    Serial.print(projectedTempDS18B20, 2);
    Serial.print(", Projected Analog Temp: ");
    Serial.println(projectedTempAnalog, 2);

    // Sprawdzenie alarmów
    ds18b20AlertActive = false;
    analogAlertActive = false;

    if (!isnan(ds18b20Temp) && ds18b20Temp >= TEMP_HIGH_THRESHOLD) {
      ds18b20AlertActive = true;
      Serial.println("ALERT: DS18B20 Temp reached threshold!");
    } else if (!isnan(projectedTempDS18B20) && projectedTempDS18B20 >= TEMP_HIGH_THRESHOLD && !isnan(ds18b20Temp) && ds18b20Temp < TEMP_HIGH_THRESHOLD) {
      ds18b20AlertActive = true;
      Serial.println("ALERT: Rising trend for DS18B20 predicts temp will reach threshold soon!");
    }

    if (!isnan(analogTemperature) && analogTemperature >= TEMP_HIGH_THRESHOLD) {
      analogAlertActive = true;
      Serial.println("ALERT: Analog Temp reached threshold!");
    } else if (!isnan(projectedTempAnalog) && projectedTempAnalog >= TEMP_HIGH_THRESHOLD && !isnan(analogTemperature) && analogTemperature < TEMP_HIGH_THRESHOLD) {
      analogAlertActive = true;
      Serial.println("ALERT: Rising trend for Analog Temp predicts temp will reach threshold soon!");
    }

    if (ds18b20AlertActive || analogAlertActive) {
      alarmStatusChar = 'A';
    } else {
      alarmStatusChar = 'N';
    }


    // Sterowanie chłodzeniem
    if (digitalRead(coolingPin) == LOW) {             // Chłodzenie WYŁĄCZONE
      if (ds18b20AlertActive || analogAlertActive) {  // Włącz, jeśli któryś alarm aktywny
        digitalWrite(coolingPin, HIGH);
        d5ControlStatusChar = 'W';
        Serial.println("INFO D5 Control: Cooling ON!");
      }
    } else {  // Chłodzenie WŁĄCZONE
      bool ds18b20BelowHysteresis = (!isnan(ds18b20Temp) && ds18b20Temp <= coolingOffThreshold && projectedTempDS18B20 <= TEMP_HIGH_THRESHOLD);
      if (isnan(ds18b20Temp) && !ds18b20AlertActive) ds18b20BelowHysteresis = true;

      bool analogBelowHysteresis = (!isnan(analogTemperature) && analogTemperature <= coolingOffThreshold && projectedTempAnalog <= TEMP_HIGH_THRESHOLD);
      if (isnan(analogTemperature) && !analogAlertActive) analogBelowHysteresis = true;

      if (!ds18b20AlertActive && !analogAlertActive && ds18b20BelowHysteresis && analogBelowHysteresis) {
        digitalWrite(coolingPin, LOW);
        d5ControlStatusChar = 'n';
        Serial.println("INFO D5 Control: Cooling OFF!");
      }
    }
    float zasilane=PomiarZsailania();
    //float zasilane =14.5;
    // Wysyłanie danych przez BLE UART lub aktualizacja reklamy
    if (central) {  // Jeśli połączono, wysyłaj dane przez UART
      String plotData = String(!isnan(analogTemperature) ? analogTemperature : 0.0, 1) + "," + String(!isnan(ds18b20Temp) ? ds18b20Temp : 0.0, 1) + "," + String(zasilane, 1) + "," + String(TEMP_HIGH_THRESHOLD, 1) + "\n";
      if (txCharacteristic.subscribed()) {
        Serial.print("INFO BLE TX Plotter: Sending: '" + plotData.substring(0, plotData.length() - 1) + "' (Length: " + plotData.length() + " bytes)");
        txCharacteristic.writeValue(plotData.c_str());
        Serial.println(" - Sent OK!");
      } else {
        Serial.println("INFO BLE TX: Not subscribed, data not sent (subsc. required).");
      }
    } else {  // Jeśli nie połączono, aktualizuj dane reklamowe
      //char infoBuffer[64];
      //sprintf(infoBuffer,"co za kupa %f\n",analogTemperature);
      //Serial.println(infoBuffer);
      
      updateAdvertisingData();

      //sprintf(infoBuffer,"co za dupa %f\n",analogTemperature);

    }
  }
}

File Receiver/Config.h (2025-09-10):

#ifndef CONFIG_H
#define CONFIG_H

#include <Arduino.h>

// --- Definicje Pinow dla XIAO nRF52840 ---
#define TFT_CS                  3   
#define TFT_DC                  6   
#define TFT_RST                 7   
#define TFT_BL                  D0  
#define LIGHT_SENSOR_PIN        A1  // Prawidlowe uzycie pinu A1/D1 dla fotorezystora
#define COOLING_PIN             D5  
#define LED_RED_PIN             LED_BUILTIN 
#define LED_BLUE_PIN            LEDB        
#define BUZZER_PIN              D9

// --- Konfiguracja ADC ---
const float ADC_MAX_VOLTAGE = 3.3; 
const int MY_ADC_RESOLUTION_VALUE = 4096; 

// --- Konfiguracja trybow pracy i kalibracji ---
const unsigned long CALIBRATION_INTERVAL_MS = 40000;
const unsigned long CALIBRATION_DURATION_MS = 1000; 
const unsigned long NORMAL_DURATION_MS = 9000;      

// --- Konfiguracja odczytow jasnosci i jej adaptacji ---
const unsigned long LIGHT_READ_INTERVAL_MS = 1000; 
const unsigned long BRIGHTNESS_UPDATE_INTERVAL_MS = 5000;
const int CONSECUTIVE_SAMPLES_THRESHOLD = 5; 

// --- Stałe progowe dla wentylatora i alarmu ---
#define WENTYLATOR_TEMP_THRESHOLD 66.0 // Stała temperatura włączenia wentylatora
#define ALARM_TEMP_THRESHOLD      70.0 // Stała temperatura włączenia alarmu

#endif

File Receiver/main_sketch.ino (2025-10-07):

#include <bluefruit.h>  // ✨ Kluczowa zmiana: dołącz to najpierw
#include "simulation.h"
#include "LCD_Display.h"
#include "bmp280_sensor.h"
#include "imu_sensor.h"
#include "light_sensor_control.h"  // Dodałem ten wiersz, aby naprawić błąd
#include "ble_control.h"           // <-- WAZNE: Dołączenie nowego pliku nagłówkowego
#include "alarm_handler.h"
#include "Config.h"
#include "virtual_button.h"



// --- Zmienne globalne do sterowania kalibracja ---
unsigned long lastCalibrationToggleTime = 0;

// Instancja struktury danych, ktora bedzie wypelniana
DisplayData currentDisplayData;
bool Button = false;

void setup() {
  // Ustawiamy zrodlo danych w setup() - dla IMU zawsze Real

#if 1
  currentDisplayData.MainTemperature.source = Real;
  currentDisplayData.MainAngle.source = Real;
  currentDisplayData.MainRssi.source = Real;
  currentDisplayData.MainHeight.source = Real;
  currentDisplayData.MainVoltage.source = Real;
  currentDisplayData.MainCalibrate.Source = Real;
  currentDisplayData.MainTempeSource.source = Real;
  currentDisplayData.Alarm.source = Real;
  currentDisplayData.Wentylator.source = Real;
  #else
  currentDisplayData.MainTemperature.source = Simul;
  currentDisplayData.MainAngle.source = Simul;
  currentDisplayData.MainRssi.source = Simul;
  currentDisplayData.MainHeight.source = Simul;
  currentDisplayData.MainVoltage.source = Simul;
  currentDisplayData.MainCalibrate.Source = Simul;
  currentDisplayData.MainTempeSource.source = Simul;
  currentDisplayData.Alarm.source = Simul;
  currentDisplayData.Wentylator.source = Simul;
  #endif 


  // Inicjalizujemy na wypadek niepowodzenia odczytu z czujnika
  currentDisplayData.MainAngle.RealAngle = -1;
  currentDisplayData.MainHeight.RealHeght = -1;

  currentDisplayData.MainTempeSource.DigitalStatus=-1;
  currentDisplayData.MainTempeSource.AnalogStatus=-1;


  currentDisplayData.MainCalibrate.CalibrationConuter = 20;

  Serial.begin(115200);
  int counterWait=0;
    
  while (!Serial && counterWait<10)
  {
    delay(100); 
    counterWait++;
  }

  Serial.println("-----------------------------------Starting application--------------------------------------");

  Serial.println("Inicjalizacja LCD...");
  LCD_init();
  Serial.println("LCD zainicjalizowany.");

  setBacklightPWM(255);
  Serial.println("Podswietlenie LCD ustawione na max.");

  if (!initBmp280()) {
    Serial.println(F("Inicjalizacja BMP280 nie powiodla sie! Program bedzie uzywal danych symulacyjnych."));
    tft.fillScreen(ST77XX_BLACK);
    tft.setCursor(10, (tft.height() / 2) - 20);
    tft.setTextSize(2);
    tft.setTextColor(ST77XX_WHITE);
    tft.print(F("BMP280 init failed!"));
    delay(2000);
    tft.fillScreen(ST77XX_BLACK);
  } else {
    Serial.println(F("BMP280 zainicjowany pomyslnie."));
  }

  // Proba inicjalizacji IMU. Nie zmieniamy zrodla danych, jesli sie nie powiedzie.
  if (!imu_init()) {
    Serial.println(F("Inicjalizacja IMU nie powiodla sie!"));
  } else {
    Serial.println(F("IMU zainicjalizowany pomyslnie."));
  }
  if(LoadImuCalibration()==false)
  {
    int i;
    for(i=0;i<4;i++)
    {
      int timeTone=200;
      tone(BUZZER_PIN, 750, timeTone);
      delay(timeTone*2);
    }
    setCallIMUasZero();  
  }
  // --- WYWOŁANIE FUNKCJI INICJALIZUJĄCEJ BLUETOOTH ---
  ble_init();
  pinMode(LIGHT_SENSOR_PIN, INPUT);
  analogReadResolution(12);
  lastCalibrationToggleTime = millis();
}

void loop() {
  static unsigned long lastUpdateTimestamp = 0;  // Nowa zmienna dla timera
  unsigned long currentTime = millis();

  // 1. Cykliczne zadania - wykonywane co 1000ms
  if (currentTime - lastUpdateTimestamp >= 1000) {
    lastUpdateTimestamp = currentTime;  // Zapisz czas nowej aktualizacji

    // Przetwarzanie danych z BMP280
    Bmp280Data bmpData;
    bool bmpReadSuccess = readBmp280Data(&bmpData);
    if (bmpReadSuccess) {
      currentDisplayData.MainHeight.RealHeght = (int)bmpData.altitude;
    } else {
      currentDisplayData.MainHeight.RealHeght = -1;
    }

    // Przetwarzanie danych z IMU
    if (currentDisplayData.MainAngle.source == Real) {
      IMUData imuData;
      if (readIMUData(&imuData)) {
        currentDisplayData.MainAngle.RealAngle = (int)roundf(/*abs*/(imuData.tilt) / 90.0 * 100.0);
        currentDisplayData.x_acel=imuData.X;
        currentDisplayData.y_acel=imuData.Y;
        currentDisplayData.z_acel=imuData.Z;
        currentDisplayData.MainAngle.Valid=true;
      }
    }
    if (currentDisplayData.MainCalibrate.CalibrationConuter > 0) {
      currentDisplayData.MainCalibrate.CalibrationConuter--;
      if (Button == true || currentDisplayData.MainCalibrate.RealCalibrate == true) {
        setAbsoluteHighest(270);  // Kalibracja wysokosci na 270m
        Call_IMU_Calibration(1);   // Kalibracja zyroskopu z zapisem do QSPI
        Serial.print("kalibaracja czujnikow]\n");
        tone(BUZZER_PIN, 500, 100);
        currentDisplayData.MainCalibrate.RealCalibrate = true;
        if (Button == true) {
          sprintf(currentDisplayData.MainCalibrate.TextValue, "Kalibr Manualna");
        }
        currentDisplayData.MainCalibrate.CalibrationConuter=0;
      } else tone(BUZZER_PIN, 500, 10);
    }

    // Przetwarzanie i symulacja danych
    ble_task(&currentDisplayData);
    Button = readVirtualButton();
    if (Button == true) {
      static int countButton = 0;
      Serial.printf("Push Button %d\n", ++countButton);
      tone(BUZZER_PIN, 1000, 10);
    }
    simulateSensorData(&currentDisplayData, currentTime);
    debugPrintSimulatedData(&currentDisplayData);

    // Obsługa kontroli jasności
    handleBrightnessControl(&currentDisplayData, currentTime);

    static int intTimeerPopupWindow=0;
    intTimeerPopupWindow++;
    if((intTimeerPopupWindow%(60*5))==0)
    {
      //currentDisplayData.MainTempeSource.AnalogStatus=-1;
      //currentDisplayData.MainTempeSource.DigitalStatus=-1;
        currentDisplayData.textPopup[0]=0;
        if(currentDisplayData.MainTempeSource.AnalogStatus==-1)
        {
            sprintf(currentDisplayData.textPopup,"A-> ");
            currentDisplayData.popUpWindow=true;
        }
        if(currentDisplayData.MainTempeSource.DigitalStatus==-1)
        {
            sprintf(currentDisplayData.textPopup+strlen(currentDisplayData.textPopup),"D-> ");
            currentDisplayData.popUpWindow=true;
            
        }
        if(currentDisplayData.popUpWindow==true)
        {
            sprintf(currentDisplayData.textPopup+strlen(currentDisplayData.textPopup),"ERR"); 
            tone(BUZZER_PIN, 1000, 10);       //synalizacja że jest jakiś komunikat
        }
    }
    //currentDisplayData.MainTemperature.temperature=918;
    // Aktualizacja wyświetlacza
    LCD_PUT(&currentDisplayData);
    currentDisplayData.popUpWindow=false;
    currentDisplayData.MainCalibrate.TextValue[0] = 0;
    if (currentDisplayData.MainCalibrate.RealCalibrate == true) {
      currentDisplayData.MainCalibrate.RealCalibrate = false;
    }
  }
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

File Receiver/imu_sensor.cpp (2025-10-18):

#include "imu_sensor.h"
#include <Arduino.h>
#include <Wire.h>
#include <LSM6DS3.h>
#include "ConfigurationStorage.h"  // Używa funkcji saveConfig i loadConfig

#define CTRL8_XL 0x17
#define CTRL6_C 0x15
#define CTRL7_G 0x16
#define LSM6DS3_ADDR 0x6A
#define CALIBRATION_BLOCK 0

LSM6DS3 myIMU(I2C_MODE, LSM6DS3_ADDR);

static float kalman_angle = 0;
static float kalman_bias = 0;
static float kalman_P[2][2] = { { 0, 0 }, { 0, 0 } };

// ZMIENNE ZINICJALIZOWANE POPRAWNYMI STAŁYMI Z PLIKU .h

// Zmienna LPF do użycia w CollectImu()
static const float ACCEL_LPF_ALPHA = ACCEL_LPF_ALPHA_set;

// Zmienna, ktora jest dynamicznie zmieniana w CollectImu()
static float R_measure = R_measure_low_set; 

static const float Q_angle_base = Q_angle_set;
static const float Q_bias_low = Q_bias_low_set;
static const float Q_bias_high = Q_bias_high_set;

// Poniższe statyczne stałe muszą być użyte w logice adaptacyjnej (CollectImu)
static const float ACCEL_TOLERANCE = ACCEL_TOLERANCE_set;
static const float R_measure_high = R_measure_high_set;
static const float R_measure_low = R_measure_low_set;
static const float GYRO_THRESHOLD = GYRO_THRESHOLD_set;

// Te zmienne są używane w funkcjach get i CollectImu()
static float pitch_offset = 0;
static float accel_norm_debug = 0;
static bool movment = false;
static float X=0, Y=0, Z=0;
static int probe = 0;
static float filtered_accel_x = 0;
static float filtered_accel_z = 0;

// ======================================================================
// ZMIENNE KALIBRACYJNE (NOWA STRUKTURA)
// ======================================================================
static float roll_offset = 0.0;
static float g_x_offset = 0.0;  // NOWA: Statyczna wartość grawitacji X (PIONOWA)
static float g_z_offset = 0.0;  // NOWA: Statyczna wartość grawitacji Z (KIERUNEK JAZDY)
static float gyro_bias_offset=0.0;  //zapisany dryft z kalibracji 

static const float default_roll_offset = 0.0;
static const float default_pitch_offset = 0.0;
static const float default_g_x_offset = 1.0f;
static const float default_g_z_offset = 0.0f;


// ======================================================================
// FUNKCJE POMOCNICZE (BEZ ZMIAN)
// ======================================================================
bool getGyroState(float* rawGyro) {
  *rawGyro = kalman_bias;
  return movment;
}

static void initHWFilter() {
  Serial.println("Konfiguracja filtrow sprzetowych IMU...");
  uint8_t ctrl8_xl_val = 0;
  ctrl8_xl_val |= (0b01 << 6);
  ctrl8_xl_val |= (1 << 0);

  Wire.beginTransmission(LSM6DS3_ADDR);
  Wire.write(CTRL8_XL);
  Wire.write(ctrl8_xl_val);
  Wire.endTransmission();

  uint8_t ctrl7_g_val = 0;
  ctrl7_g_val |= (1 << 4);
  ctrl7_g_val |= (0b000 << 0);

  Wire.beginTransmission(LSM6DS3_ADDR);
  Wire.write(CTRL7_G);
  Wire.write(ctrl7_g_val);
  Wire.endTransmission();

  Serial.println("Filtry sprzetowe zostaly skonfigurowane.");
}

void Kalman_init(float initial_angle) {
  kalman_angle = initial_angle;
  kalman_bias = 0;
  kalman_P[0][0] = 1;
  kalman_P[0][1] = 0;
  kalman_P[1][0] = 0;
  kalman_P[1][1] = 1;
}

void Kalman_update(float newAngle, float newRate, float dt, float current_Q_angle, float current_Q_bias) {
  kalman_angle += dt * (newRate - kalman_bias);
  kalman_P[0][0] += dt * (dt * kalman_P[1][1] - kalman_P[0][1] - kalman_P[1][0] + current_Q_angle);
  kalman_P[0][1] -= dt * kalman_P[1][1];
  kalman_P[1][0] -= dt * kalman_P[1][1];
  kalman_P[1][1] += dt * current_Q_bias;
  float y = newAngle - kalman_angle;
  float S = kalman_P[0][0] + R_measure;
  float K[2];
  K[0] = kalman_P[0][0] / S;
  K[1] = kalman_P[1][0] / S;
  kalman_angle += K[0] * y;
  kalman_bias += K[1] * y;
  float P00_temp = kalman_P[0][0];
  float P01_temp = kalman_P[0][1];
  kalman_P[0][0] -= K[0] * P00_temp;
  kalman_P[0][1] -= K[0] * P01_temp;
  kalman_P[1][0] -= K[1] * P00_temp;
  kalman_P[1][1] -= K[1] * P01_temp;
}

// ======================================================================
// OBSŁUGA PAMIĘCI FLASH (ZMODYFIKOWANE)
// ======================================================================
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

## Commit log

2025-09-04 Create 3D.md
    Create subfolder for 3D housing
2025-09-04 Create Calibrator.md
    Create calibrator project
2025-09-04 Add files via upload
    Add freecad 3d models
    [LCD_bottomV1.FCstd, LCD_topV1.FCstd, TempSensorPTC100.FCstd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]
2025-09-05 Update Calibrator.md
    Update description how it work
2025-09-05 Update Calibrator.md
    Deltete polish text for AI
2025-09-05 Update Readme.md
    Add info about calibrator
2025-09-10 Add files via upload
    Add ready to use 3d model for all components
    [LCD_bottomV1-Body.stl, LCD_topV1-Body.stl, TempSensorPTC100-Body.stl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]
2025-09-10 Add files via upload
    start cod for calibrator
2025-09-11 Add custom DS18B20 Probe
    Cooper M8 standard for cable how to do
2025-09-12 Add schematic of transmiter
    Some resistors especially in voltage devider and amplifier Gain need adjust ! (No use variable resistor) only high precision and high stability, because of
    we need stability in long time, and wide ambient thermal window
2025-09-13 new Update
    Resolve problem with virtual button when very bright add dynamic Bias level , Resolve problem with calibration saving now when fail after read then auto-calibrate on current IMU position as zero, and four short beep appear , Add advanced hardware filtering and Kalman filter for stability profile road based on IMU. ADD, Isolate IMU/save-read calibration. Improve when start no need serial for properly work .
    [ConfigurationStorage.h]
2025-09-14 optimize for standard neodymium magnet 10x1mm for easy mount
    [LCD_bottomV1-Body.stl, LCD_bottomV1.FCStd, LCD_topV1.FCStd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]
2025-09-14 Add active buzzer schmatic
    All components are inside of buzzer as SMD (black glue was used for stability )
2025-09-14 add alternative version top of LCD housing
    update flexible support hold for LCD Display
    [LCD_topV2-Body.stl, LCD_topV2.FCStd]
2025-09-15 Create PCB Readme.md
2025-09-15 Add production files
    Based on this files you can order PCB everywhere.
    [PT100v1.GBL, PT100v1.GBP, PT100v1.GBS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]
2025-09-15 Delete ExtraInfo/PCBTransmiter.wmv
    Not supported by github
2025-09-16 Update PCB hardware info
2025-09-24 update
    Resolve problem wit configuration saving, fast refresh LCD =20% faster, update and add lowPass filer and data fusion imu for road angle mesurment, disply +/- raod profile
    [LCD_Display.cpp, LCD_Display.h, imu_sensor.cpp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]
2025-09-24 Kalman filter new settings
    add in H file predefinition for kalmann filter and other setting fresesh 1s instaed of 3s
2025-09-26 update kalman filter calculate
    now use dynamic DT for Kalman calculate new filter setting, RSSI update period 3s (more stable params)
2025-09-28 new Kalman filter setting improve Graph disply
    I fight with gyroscope setting (acceleration +/-20% corrupt road profile but when no acceleration- static then are OK ) improve display Temperature graph: When temperature is over 20C but less than 2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
2025-10-01 update Kalman fiter
    now the acceleration X,Z axis are displayed in small fonts on LCD, when more than limit. when no move green bar is draw, more advanced Kalman algorithm, new presets
2025-10-03 Update sensor housing (only source)
    Add Nissan logo add temperature icon sensor, thick optimise for print cost
2025-10-04 Update new Kalman and display
    New presets for Kalman Filter and method, add new font for https://rop.nl/truetype2gfx (bigger temperature fonts)
2025-10-06 Add graphic elements to sensor
    Optimise top of housing for sensor, add Nissan logo and some graphics element for indicate cable.
    [TempSensorPTC100_wieczko-Body.stl, TempSensorPTC100_wieczko.FCStd]
2025-10-06 fix bug
    wrong data X-Z mistake replaced in kalman update function
    [imu_sensor.cpp]
2025-10-07 add custom fonts
    Modified by https://tchapi.github.io/Adafruit-GFX-Font-Customiser original font for add missing ∘C character as 0x19 and turtle symbol as 0x1A. Properly display Celcius units
    [LCD_Display.cpp, LCD_Display.h, imu_sensor.h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]
2025-10-18 improve virtual button
    improve virtual button for night ride when is dark and some traffic lamp can trigger (armed) the button
2026-01-23 Add files via upload
    improvmets: save and call calibrated altitude, inclinometer send gyro bias and compensate during work, new algorithm for kalman calculation
